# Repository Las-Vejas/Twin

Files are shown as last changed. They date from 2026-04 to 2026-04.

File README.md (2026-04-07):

# Twin
A macropad for both your computer and Home Assistant. Controls PC as an HID device, controls Home Assistant via ESPHome. 

I built this because I wanted a central place to control both my home/room, and my computer at the same time.
This device switches between the Home Assistant mode and PC mode with a click of a button and you receive all the feedback through the 25 leds on board.

This macropad contains:
- 14 underglow leds
- 11 switches (with leds underneath)
- RP2040
- ESP32-C6
- 1 rotary encoder

## Images

### Schematic


### PCB




## BOM

|Id |Footprint |Designation |LCSC |Amount|Price |Link |
|---|---|---|---|---|---|---|
|1  |C_0402_1005Metric |1uf |C14445 |100 |0.23 $US |https://www.lcsc.com/product-detail/C14445.html |
|2  |C_0402_1005Metric |100nf |C60474 |100 |0.10 $US |https://www.lcsc.com/product-detail/C60474.html |
|3  |C_0402_1005Metric |10uf |C315248  |20 |0.17 $US |https://www.lcsc.com/product-detail/C315248.html |
|4  |C_0402_1005Metric |33pf |C107005  |100 |0.12 $US |https://www.lcsc.com/product-detail/C107005.html |
|7  |LED_WS2812B-2020_PLCC4_2.0x2.0mm |WS2812B-2020 |C965555  |40 |3.59 $US |https://www.lcsc.com/product-detail/C965555.html |
|8  |D_SOD-323_HandSoldering |D_Small |C191023  |50 |0.52 $US |https://www.lcsc.com/product-detail/C191023.html |
|9  |MX_SK6812MINI-E |LED_SK6812MINI |C5149201 |55 |4.13 $US |https://www.lcsc.com/product-detail/C5149201.html |
|10 |USB_C_Receptacle_GCT_USB4105-xx-A_16P_TopMnt_Horizontal|USB_C_Receptacle_USB2.0_16P|C2765186 |20 |1.23 $US |https://www.lcsc.com/product-detail/C2765186.html |
|12 |C_0402_1005Metric |10k |C60490 |100 |0.08 $US |https://www.lcsc.com/product-detail/C60490.html |
|13 |C_0402_1005Metric |5.1k |C105872  |100 |0.09 $US |https://www.lcsc.com/product-detail/C105872.html |
|14 |C_0402_1005Metric |27 |C138021  |100 |0.08 $US |https://www.lcsc.com/product-detail/C138021.html |
|15 |C_0402_1005Metric |1k |C106235  |100 |0.08 $US |https://www.lcsc.com/product-detail/C106235.html |
|16 |C_0402_1005Metric |47 |C137973  |100 |0.09 $US |https://www.lcsc.com/product-detail/C137973.html |
|17 |SW_Push_SPST_NO_Alps_SKRK |SW_Push |C115357  |10 |1.31 $US |https://www.lcsc.com/product-detail/C115357.html |
|18 |RotaryEncoder_Alps_EC11E-Switch_Vertical_H20mm |RotaryEncoder_Switch |C470742  |5 |9.36 $US |https://www.lcsc.com/product-detail/C470742.html |
|19 |Choc_V1V2_1.00u |Choc | |20 |13.22 $US|https://fr.aliexpress.com/item/1005008651091078.html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|
|21 |SOT-23 |MCP1700x-300xxTT |C39051 |5 |1.88 $US |https://www.lcsc.com/product-detail/C39051.html |
|22 |ESP32-C6-MINI-1 |ESP32-C6-MINI-1 |C5736265 |5 |11.97 $US|https://www.lcsc.com/product-detail/C5736265.html |
|23 |QFN-56-1EP_7x7mm_P0.4mm_EP3.2x3.2mm |RP2040 |C2040 |5 |4.74 $US |https://www.lcsc.com/product-detail/C2040.html |
|24 |Winbond_USON-8-1EP_3x2mm_P0.5mm_EP0.2x1.6mm |W25Q16JVSS |C5258281 |10 |2.74 $US |https://www.lcsc.com/product-detail/C5258281.html |
|25 |Crystal_SMD_3225-4Pin_3.2x2.5mm |12MHz |C20625731|5 |1.45 $US |https://www.lcsc.com/product-detail/C20625731.html |
| |PCB | | |5 |7.00 $US |jlcpcb.com |
| |Stencil | | |1 |3.05 $US |jlcpcb.com |
| |PCB Shipping | | |1 |15.00 $US|jlcpcb.com |
| | | | | |81.90 $US| |

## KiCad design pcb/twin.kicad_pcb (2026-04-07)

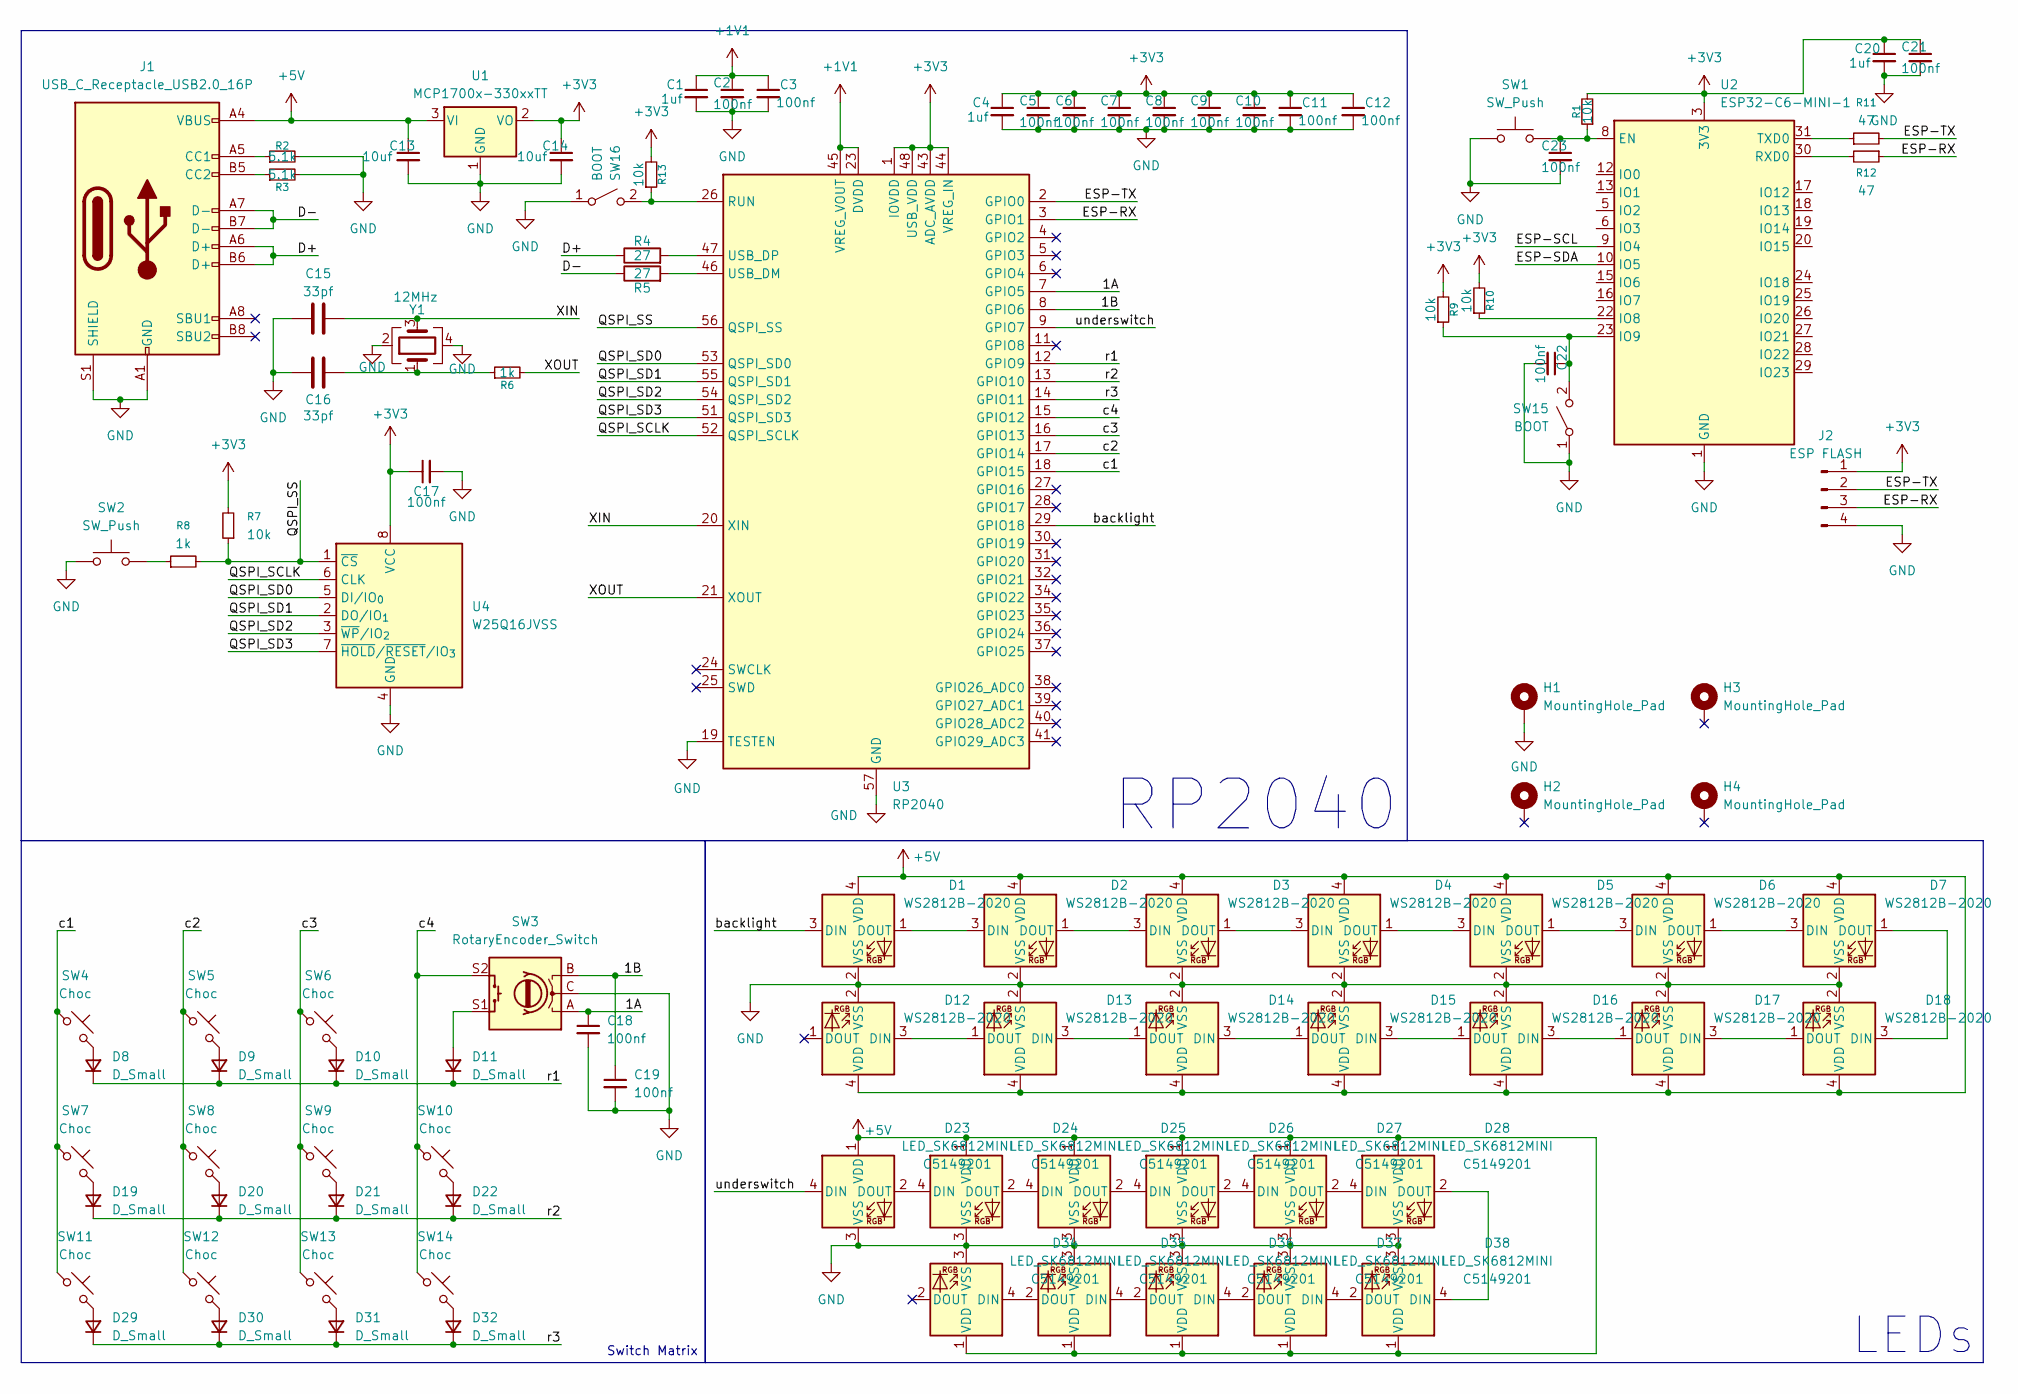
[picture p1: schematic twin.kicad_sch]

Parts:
C1, C4, C20: 1uf; C_0402_1005Metric
C2, C3, C5, C6, C7, C8, C9, C10, C11, C12, C17, C18, C19, C21, C22, C23: 100nf; C_0402_1005Metric
C13, C14: 10uf; C_0402_1005Metric
C15, C16: 33pf; C_0402_1005Metric
D1: WS2812B-2020; LED_WS2812B-2020_PLCC4_2.0x2.0mm; LCSC Part # C2976072
D2, D3, D4, D5, D6, D7, D12, D13, D14, D15, D16, D17, D18: WS2812B-2020; LED_WS2812B-2020_PLCC4_2.0x2.0mm
D8, D9, D10, D11, D19, D20, D21, D22, D29, D30, D31, D32: D_Small; D_SOD-323_HandSoldering
D23, D24, D25, D26, D27, D28, D34, D35, D36, D37, D38: LED_SK6812MINI; MX_SK6812MINI-E; LCSC C5149201
H1, H2, H3, H4: MountingHole_Pad; MountingHole_2.2mm_M2_DIN965_Pad
J1: USB_C_Receptacle_USB2.0_16P; USB_C_Receptacle_GCT_USB4105-xx-A_16P_TopMnt_Horizontal
J2: ESP FLASH; PinHeader_1x04_P2.54mm_Vertical
R1, R7, R9, R10, R13: 10k; C_0402_1005Metric
R2, R3: 5.1k; C_0402_1005Metric
R4, R5: 27; C_0402_1005Metric
R6, R8: 1k; C_0402_1005Metric
R11, R12: 47; C_0402_1005Metric
SW1, SW2: SW_Push; SW_Push_SPST_NO_Alps_SKRK
SW3: RotaryEncoder_Switch; RotaryEncoder_Alps_EC11E-Switch_Vertical_H20mm
SW4, SW5, SW6, SW7, SW8, SW9, SW10, SW11, SW12, SW13, SW14: Choc; Choc_V1V2_1.00u
SW15, SW16: BOOT; SW_Push_SPST_NO_Alps_SKRK
U1: MCP1700x-330xxTT; SOT-23
U2: ESP32-C6-MINI-1
U3: RP2040; QFN-56-1EP_7x7mm_P0.4mm_EP3.2x3.2mm
U4: W25Q16JVSS; Winbond_USON-8-1EP_3x2mm_P0.5mm_EP0.2x1.6mm
Y1: 12MHz; Crystal_SMD_3225-4Pin_3.2x2.5mm

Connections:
+1V1: C1.1, C2.1, C3.1, U3.23 (DVDD), U3.45 (VREG_VOUT), U3.50 (DVDD)
+3V3: C4.1, C5.1, C6.1, C7.1, C8.1, C9.1, C10.1, C11.1, C12.1, C14.1, C17.1, C20.1, C21.1, J2.1, R1.2, R7.2, R9.2, R10.2, R13.2, U1.2 (VO), U2.3 (3V3), U3.1 (IOVDD), U3.10 (IOVDD), U3.22 (IOVDD), U3.33 (IOVDD), U3.42 (IOVDD), U3.43 (ADC_AVDD), U3.44 (VREG_IN), U3.48 (USB_VDD), U3.49 (IOVDD), U4.8 (VCC)
+5V: C13.1, D1.4 (VDD), D2.4 (VDD), D3.4 (VDD), D4.4 (VDD), D5.4 (VDD), D6.4 (VDD), D7.4 (VDD), D12.4 (VDD), D13.4 (VDD), D14.4 (VDD), D15.4 (VDD), D16.4 (VDD), D17.4 (VDD), D18.4 (VDD), D23.1 (VDD), D24.1 (VDD), D25.1 (VDD), D26.1 (VDD), D27.1 (VDD), D28.1 (VDD), D34.1 (VDD), D35.1 (VDD), D36.1 (VDD), D37.1 (VDD), D38.1 (VDD), J1.A4 (VBUS), J1.A9 (VBUS), J1.B4 (VBUS), J1.B9 (VBUS), U1.3 (VI)
/1A: C18.1, SW3.A, U3.7 (GPIO5)
/1B: C19.1, SW3.B, U3.8 (GPIO6)
/D+: J1.A6 (D+), J1.B6 (D+), R4.1
/D-: J1.A7 (D-), J1.B7 (D-), R5.1
/ESP-RX: J2.3, R12.1, U3.3 (GPIO1)
/ESP-SCL: U2.9 (IO4)
/ESP-SDA: U2.10 (IO5)
/ESP-TX: J2.2, R11.2, U3.2 (GPIO0)
/QSPI_SCLK: U3.52 (QSPI_SCLK), U4.6 (CLK)
/QSPI_SD0: U3.53 (QSPI_SD0), U4.5 (DI/IO_{0})
/QSPI_SD1: U3.55 (QSPI_SD1), U4.2 (DO/IO_{1})
/QSPI_SD2: U3.54 (QSPI_SD2), U4.3 (~WP/IO_{2})
/QSPI_SD3: U3.51 (QSPI_SD3), U4.7 (~HOLD/~RESET/IO_{3})
/QSPI_SS: R7.1, R8.2, U3.56 (QSPI_SS), U4.1 (~CS)
/XIN: C15.2, U3.20 (XIN), Y1.3
/XOUT: R6.2, U3.21 (XOUT)
/backlight: D1.3 (DIN), U3.29 (GPIO18)
/c1: SW4.1, SW7.1, SW11.1, U3.18 (GPIO15)
/c2: SW5.1, SW8.1, SW12.1, U3.17 (GPIO14)
/c3: SW6.1, SW9.1, SW13.1, U3.16 (GPIO13)
/c4: SW3.S2, SW10.1, SW14.1, U3.15 (GPIO12)
/r1: D8.1 (K), D9.1 (K), D10.1 (K), D11.1 (K), U3.12 (GPIO9)
/r2: D19.1 (K), D20.1 (K), D21.1 (K), D22.1 (K), U3.13 (GPIO10)
/r3: D29.1 (K), D30.1 (K), D31.1 (K), D32.1 (K), U3.14 (GPIO11)
/underswitch: D23.4 (DIN), U3.9 (GPIO7)
GND: C1.2, C2.2, C3.2, C4.2, C5.2, C6.2, C7.2, C8.2, C9.2, C10.2, C11.2, C12.2, C13.2, C14.2, C15.1, C16.1, C17.2, C18.2, C19.2, C20.2, C21.2, C22.2, C23.2, D1.2 (VSS), D2.2 (VSS), D3.2 (VSS), D4.2 (VSS), D5.2 (VSS), D6.2 (VSS), D7.2 (VSS), D12.2 (VSS), D13.2 (VSS), D14.2 (VSS), D15.2 (VSS), D16.2 (VSS), D17.2 (VSS), D18.2 (VSS), D23.3 (VSS), D24.3 (VSS), D25.3 (VSS), D26.3 (VSS), D27.3 (VSS), D28.3 (VSS), D34.3 (VSS), D35.3 (VSS), D36.3 (VSS), D37.3 (VSS), D38.3 (VSS), H1.1 (1_1), J1.A1 (GND), J1.A12 (GND), J1.B1 (GND), J1.B12 (GND), J1.S1 (SHIELD), J2.4, R2.2, R3.2, SW1.1, SW2.1, SW3.C, SW15.1 (A), SW16.1 (A), U1.1 (GND), U2.1 (GND), U2.2 (GND), U2.11 (GND), U2.14 (GND), U2.36 (GND), U2.37 (GND), U2.38 (GND), U2.39 (GND), U2.40 (GND), U2.41 (GND), U2.42 (GND), U2.43 (GND), U2.44 (GND), U2.45 (GND), U2.46 (GND), U2.47 (GND), U2.48 (GND), U2.49 (GND), U2.50 (GND), U2.51 (GND), U2.52 (GND), U2.53 (GND), U3.19 (TESTEN), U3.57 (GND), U4.4 (GND), Y1.2, Y1.4
unnamed: C16.2, R6.1, Y1.1
unnamed: D1.1 (DOUT), D2.3 (DIN)
unnamed: D2.1 (DOUT), D3.3 (DIN)
unnamed: D3.1 (DOUT), D4.3 (DIN)
unnamed: D4.1 (DOUT), D5.3 (DIN)
unnamed: D5.1 (DOUT), D6.3 (DIN)
unnamed: D6.1 (DOUT), D7.3 (DIN)
unnamed: D8.2 (A), SW4.2
unnamed: D9.2 (A), SW5.2
unnamed: D10.2 (A), SW6.2
unnamed: D11.2 (A), SW3.S1
unnamed: D12.3 (DIN), D13.1 (DOUT)
unnamed: D13.3 (DIN), D14.1 (DOUT)
unnamed: D14.3 (DIN), D15.1 (DOUT)
unnamed: D15.3 (DIN), D16.1 (DOUT)
unnamed: D16.3 (DIN), D17.1 (DOUT)
unnamed: D17.3 (DIN), D18.1 (DOUT)
unnamed: D7.1 (DOUT), D18.3 (DIN)
unnamed: D19.2 (A), SW7.2
unnamed: D20.2 (A), SW8.2
unnamed: D21.2 (A), SW9.2
unnamed: D22.2 (A), SW10.2
unnamed: D23.2 (DOUT), D24.4 (DIN)
unnamed: D24.2 (DOUT), D25.4 (DIN)
unnamed: D25.2 (DOUT), D26.4 (DIN)
unnamed: D26.2 (DOUT), D27.4 (DIN)
unnamed: D27.2 (DOUT), D28.4 (DIN)
unnamed: D28.2 (DOUT), D38.4 (DIN)
unnamed: D29.2 (A), SW11.2
unnamed: D30.2 (A), SW12.2
unnamed: D31.2 (A), SW13.2
unnamed: D32.2 (A), SW14.2
unnamed: D34.4 (DIN), D35.2 (DOUT)
unnamed: D35.4 (DIN), D36.2 (DOUT)
unnamed: D36.4 (DIN), D37.2 (DOUT)
unnamed: D37.4 (DIN), D38.2 (DOUT)
unnamed: J1.A5 (CC1), R2.1
unnamed: J1.B5 (CC2), R3.1
unnamed: R8.1, SW2.2
unnamed: C22.1, R9.1, SW15.2 (B), U2.23 (IO9)
unnamed: R13.1, SW16.2 (B), U3.26 (RUN)
unnamed: C23.1, R1.1, SW1.2, U2.8 (EN)
unnamed: R10.1, U2.22 (IO8)
unnamed: R12.2, U2.30 (RXD0)
unnamed: R11.1, U2.31 (TXD0)
unnamed: R5.2, U3.46 (USB_DM)
unnamed: R4.2, U3.47 (USB_DP)

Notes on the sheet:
Switch Matrix
RP2040
LEDs

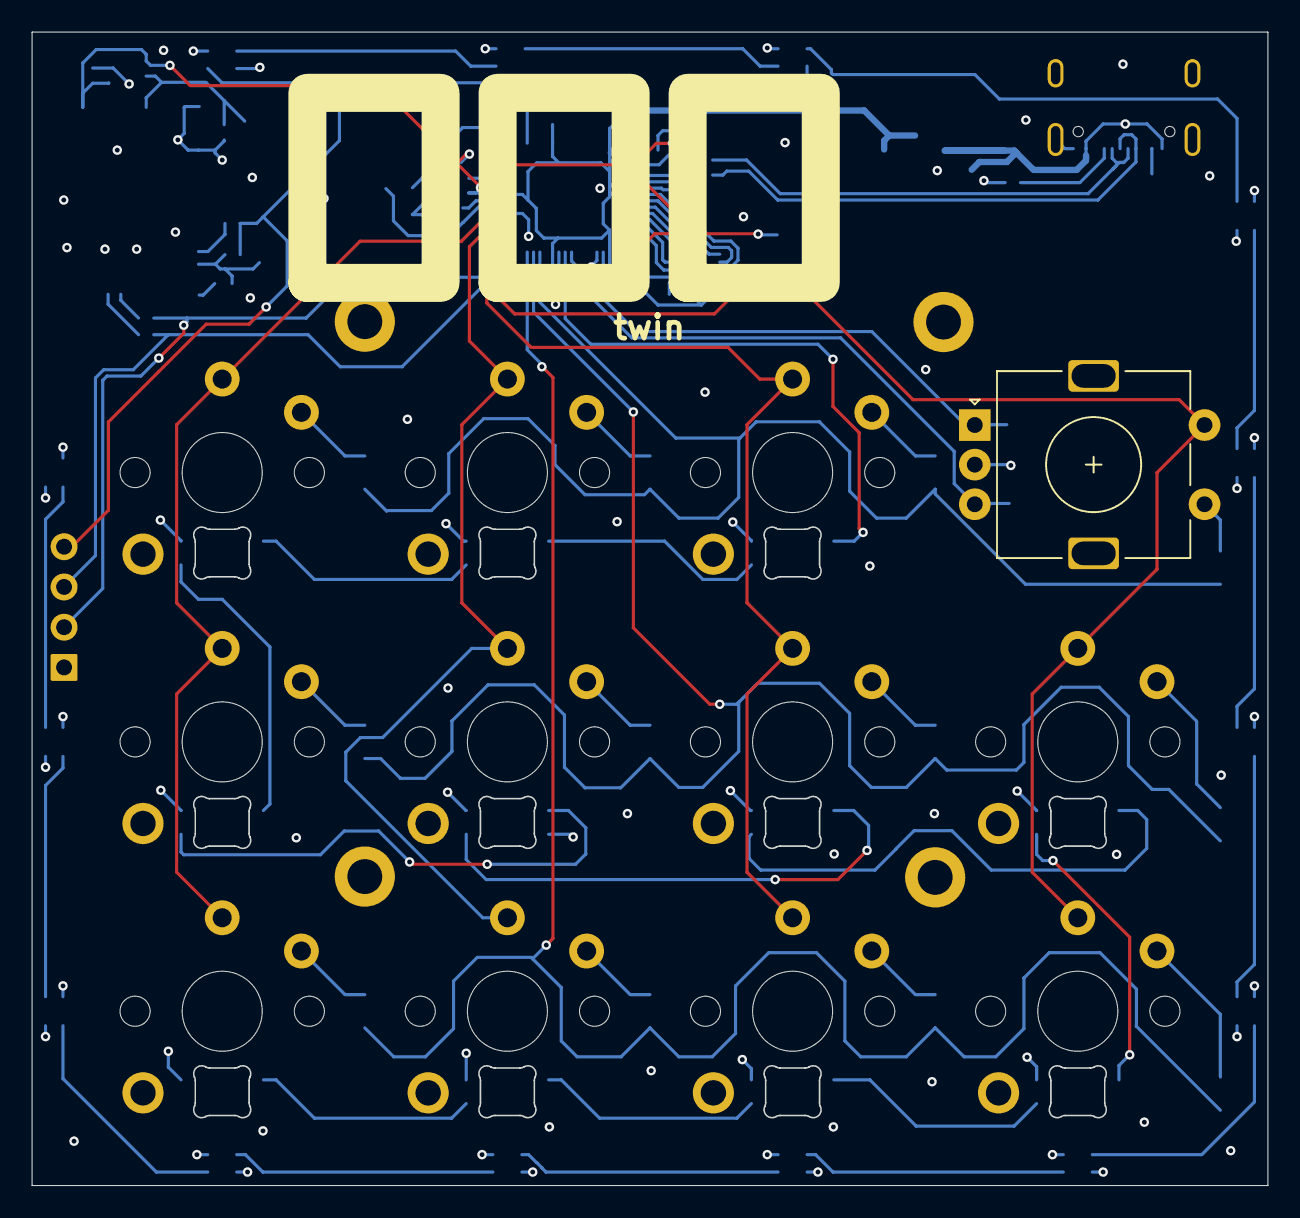
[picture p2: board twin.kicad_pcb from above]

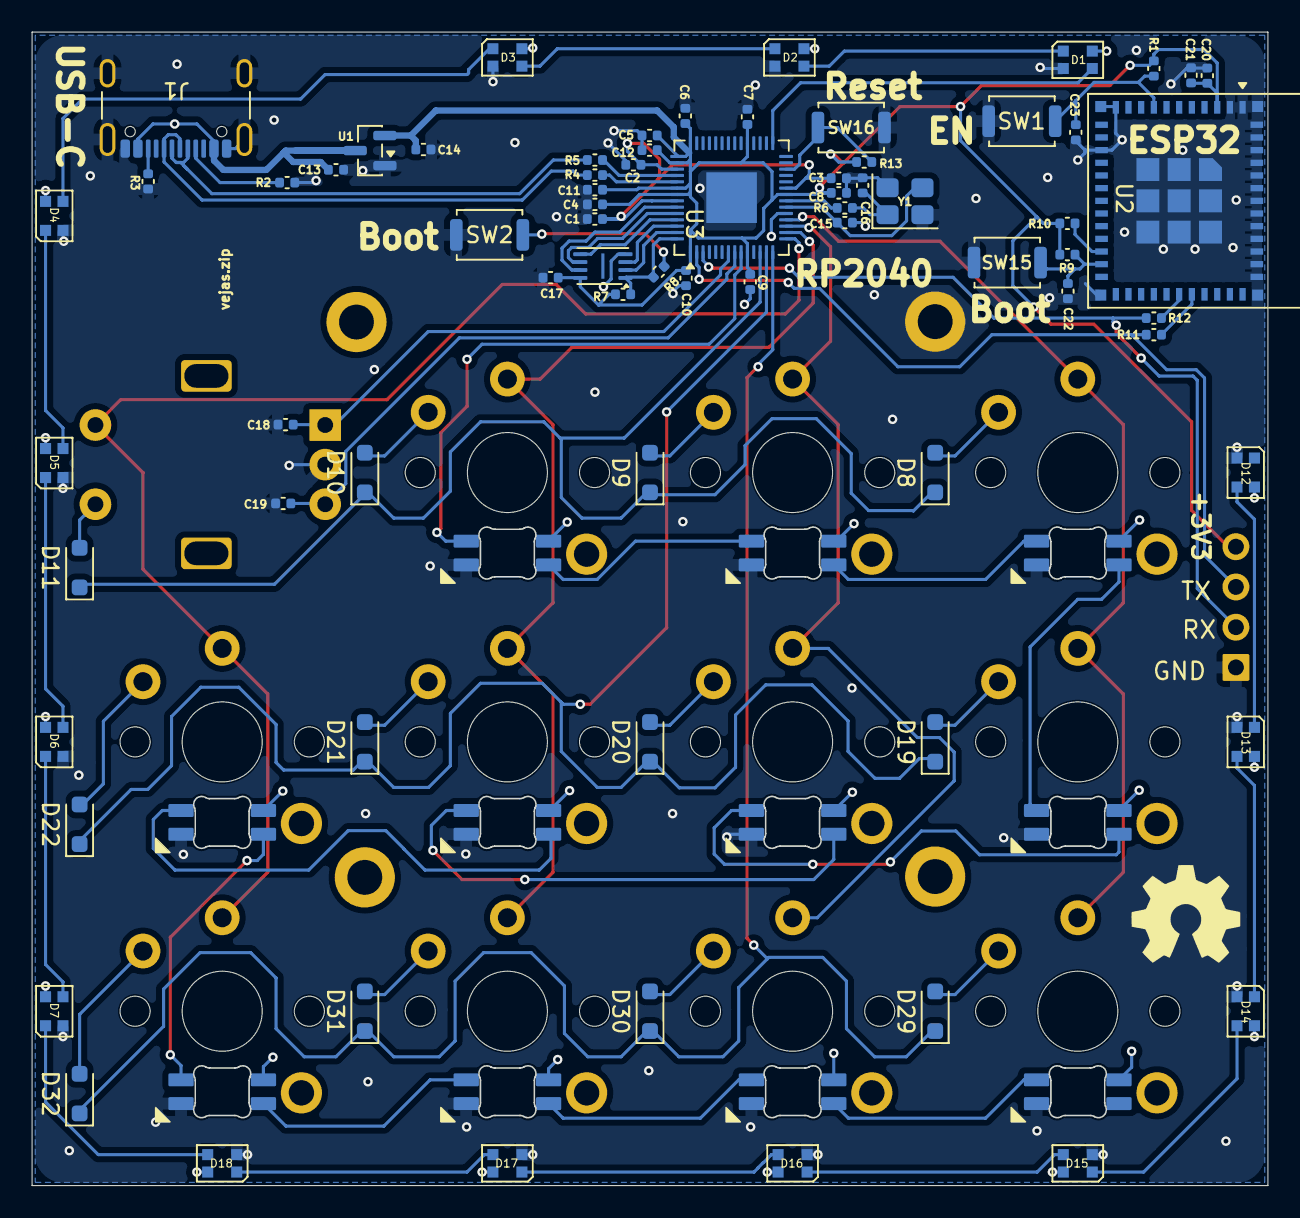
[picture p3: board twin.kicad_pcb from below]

Board: 4 copper layers, 78.0 x 72.8 mm, 100 parts (73 on the bottom side), 74 nets.

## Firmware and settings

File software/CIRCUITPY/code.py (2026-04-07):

import time
import board
from CIRCUITPY.config import *
from CIRCUITPY.matrix import KeyMatrix
from CIRCUITPY.encoder import Encoder
from CIRCUITPY.leds import LEDController
from CIRCUITPY.uart_ha import HABridge

# --- Key layout: (row, col) -> action name ---
KEYMAP = {
    (0, 0): "scene_morning",
    (0, 1): "scene_focus",
    (0, 2): "scene_evening",
    (1, 0): "media_play_pause",
    (1, 1): "toggle_light",
    (1, 2): "mute",
    (2, 0): "custom_1",
    (2, 1): "custom_2",
    (2, 2): "custom_3",
    # encoder push is handled separately
}

# Key index for underswitch LEDs (flatten row/col to index)
def key_to_led(row, col, num_cols=3):
    return row * num_cols + col

matrix  = KeyMatrix(ROW_PINS, COL_PINS)
encoder = Encoder(ENCODER_A, ENCODER_B, ENCODER_SW)
leds    = LEDController(UNDERGLOW_LED_PIN, UNDERSWITCH_LED_PIN,
                        NUM_UNDERGLOW, NUM_UNDERSWITCH)
ha      = HABridge(UART_TX, UART_RX, UART_BAUD)

# Startup: blue underglow, dim white underswitch
leds.set_underglow((0, 30, 80))
leds.set_all_underswitch((0, 20, 60, 0))

print("Macropad ready.")

while True:
    # --- Matrix events ---
    for (key, event) in matrix.get_events():
        led_idx = key_to_led(*key)
        if event == 'press':
            action = KEYMAP.get(key)
            leds.key_press_flash(led_idx)
            if action:
                ha.send(action)
                print(f"Key {key} -> {action}")
        elif event == 'release':
            leds.key_release(led_idx)

    # --- Encoder events ---
    for (_, event) in encoder.get_events():
        if event == 'cw':
            ha.send("volume", 5)
        elif event == 'ccw':
            ha.send("volume", -5)
        elif event == 'press':
            ha.send("media_play_pause")

    time.sleep(0.005)  # ~200Hz scan rate

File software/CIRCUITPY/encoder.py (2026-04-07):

import digitalio
import rotaryio

class Encoder:
    def __init__(self, pin_a, pin_b, pin_sw):
        self._enc = rotaryio.IncrementalEncoder(pin_a, pin_b)
        self._last_pos = self._enc.position
        
        self._sw = digitalio.DigitalInOut(pin_sw)
        self._sw.direction = digitalio.Direction.INPUT
        self._sw.pull = digitalio.Pull.UP
        self._sw_last = self._sw.value

    def get_events(self):
        events = []
        pos = self._enc.position
        if pos != self._last_pos:
            direction = 'cw' if pos > self._last_pos else 'ccw'
            events.append(('encoder', direction))
            self._last_pos = pos

        sw = self._sw.value
        if not sw and self._sw_last:   # active low, falling edge = press
            events.append(('encoder', 'press'))
        elif sw and not self._sw_last:
            events.append(('encoder', 'release'))
        self._sw_last = sw
        return events

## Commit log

2026-01-28 pcb files
    [twin.kicad_pcb, twin.kicad_sch]
2026-01-31 update pcb
    [twin.kicad_pcb, twin.kicad_sch]
2026-02-19 idek anymore i think more pcb stuff
    [twin.kicad_sch]
2026-02-22 Update PCB footprints and backups
    Clean up PCB repository and update the board file. Removed macOS .DS_Store and a stale KiCad schematic lock, rotated twin-backups (deleted older backup zips and added new ones). Large edits to pcb/twin.kicad_pcb: reorganized net names, replaced/updated multiple footprints (added Choc keyswitch and Alps rotary encoder footprints, changed capacitor footprints/sizes, converted several pads from SMD to thru-hole), and updated 3D model paths and footprint metadata to match recent hardware/layout changes.
    [twin.kicad_pcb, twin.kicad_sch]
2026-04-07 loads of stuff
    [twin.kicad_pcb, twin.kicad_sch]
2026-04-07 Enhance README with details, images, and BOM
    Updated the README to include additional details about the macropad's functionality and added images for schematic and PCB. Also included a BOM with component details and links.
